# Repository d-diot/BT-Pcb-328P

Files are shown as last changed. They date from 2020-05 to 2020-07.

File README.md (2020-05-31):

# d-diot BT-Pcb-328P

Kicad project files of the d-diot BT-Pcb-328P board.
The board is part of the [d-diot project](https://www.d-diot.com).
See the [blog post](https://www.d-diot.com/2019/11/09/bt-pcb-328p/) or the dedicated [wiki page](https://wiki.d-diot.com/hardware/pcb/mysensors/bt_pcb_328p) to know more about this board.

pcbfront

pcbrear

See the latest [release](https://github.com/d-diot/BT-Pcb-328P/releases) to download the gerber files to manufacture this board.

## Applications of this PCB:

[MySensors](https://www.mysensors.org/) battery powered and [3d printable](https://www.thingiverse.com/thing:3968135) wireless [Multisensor](https://wiki.d-diot.com/sensors_and_actuators/mysensors/d-diot_battery_powered_multisensor) for motion, light, temperature and humidity detection.
MySensors is compatible with a lot of open source home automation software like Home Assistant (which is the one included in the [d-diot hub](https://www.d-diot.com/2020/05/24/d-diot-hub-v-2-0/) and [image](https://www.d-diot.com/?s=d-diot+image)), OpenHAB, Domoticz, etc... See [here](https://www.mysensors.org/controller) for a complete list.

Multisensor

## Firmware

The [repository](https://github.com/d-diot/BT-Pcb-328P-firmware) of the firmware associated to this board is here.

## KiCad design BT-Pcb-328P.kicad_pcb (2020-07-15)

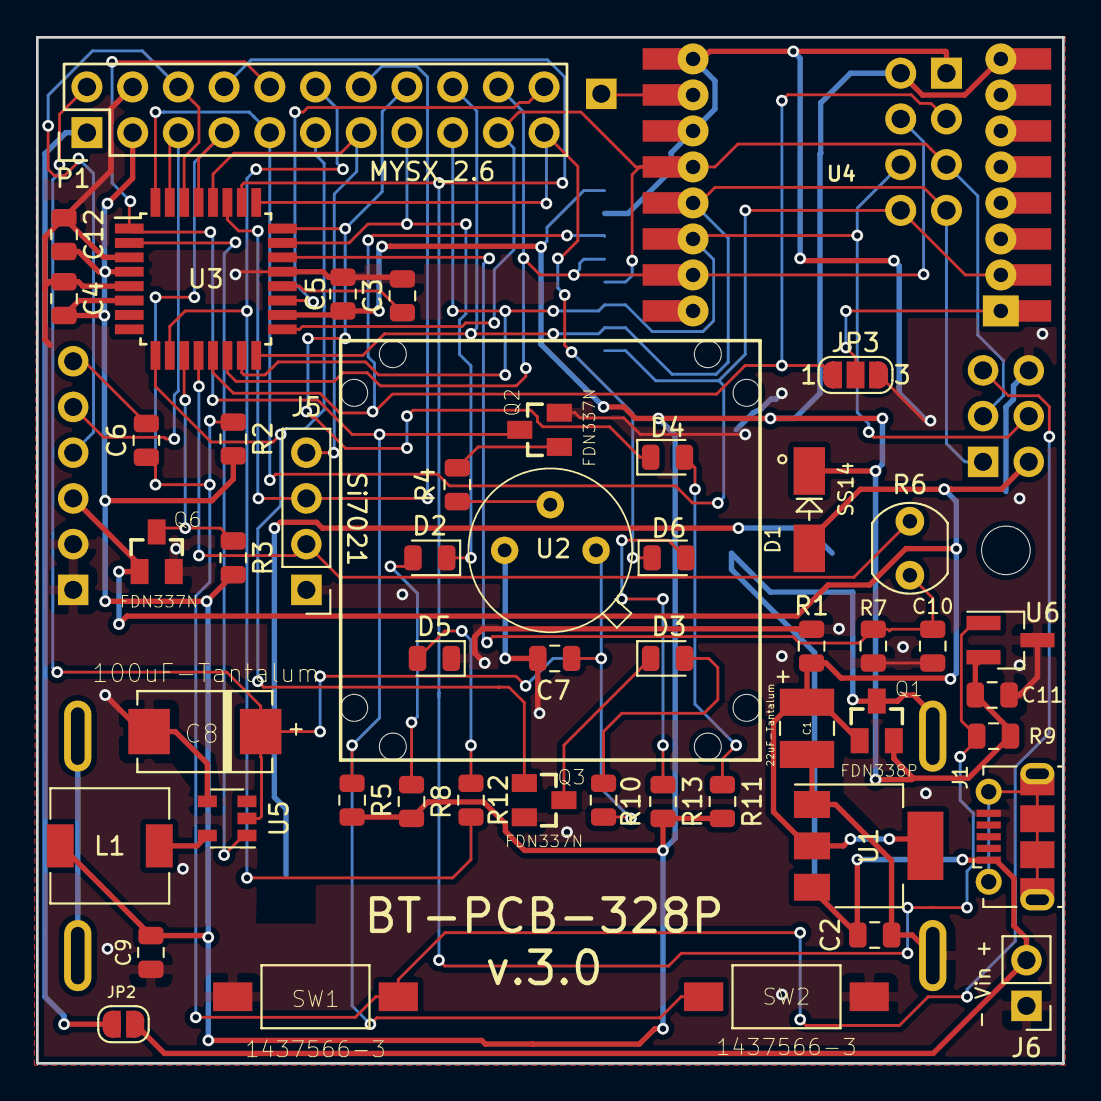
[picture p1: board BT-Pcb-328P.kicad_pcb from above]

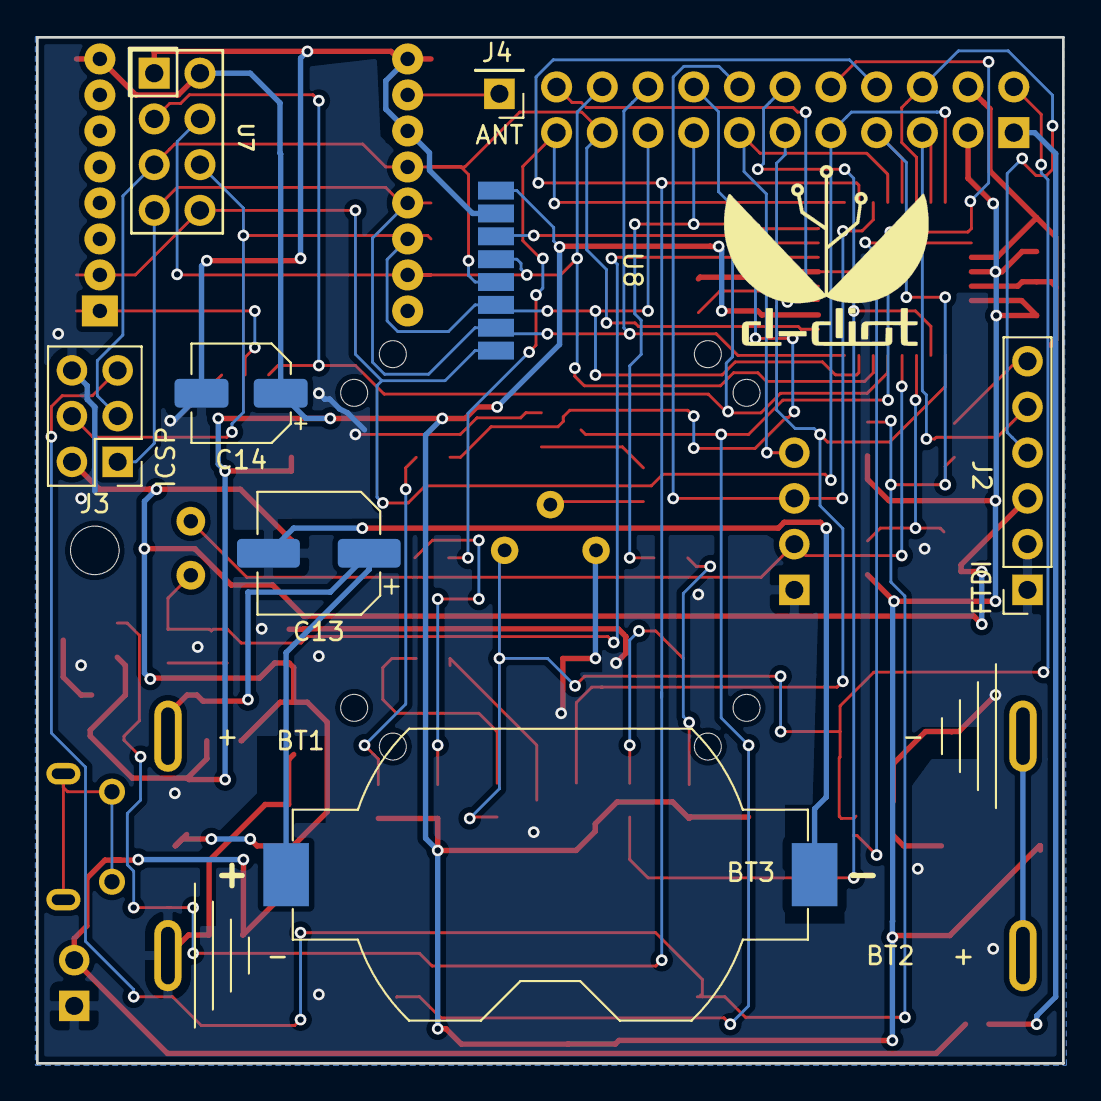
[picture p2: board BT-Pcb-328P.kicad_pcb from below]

Board: 2 copper layers, 57.0 x 57.0 mm, 60 parts (10 on the bottom side), 44 nets.

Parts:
BT1, BT2: AAA Cell; AAA-Keystone-5204-5226-NO-SILK
BT3: CR2032; BatteryHolder_Keystone_1058_1x2032
C1: 22uF-Tantalum; CAPPC3528X210N
C2, C9: 10uF; C_0805_2012Metric
C3, C4, C5, C6, C7, C10, C11, C12: 0.1uF; C_0805_2012Metric
C8: 100uF-Tantalum; TAJD107K016RNJV
C13: 100uF; CP_Elec_6.3x5.4
C14: 47uF; CP_Elec_5x5.4
D1: SS14
D2: R-LED; LED_0805_2012Metric
D3: B-LED; LED_0805_2012Metric
D4, D5: Y-LED; LED_0805_2012Metric
D6: G-LED; LED_0805_2012Metric
J1: USB_B_Micro; USB_Micro-B_Molex-105017-0001
J2: FTDI; PinSocket_1x06_P2.54mm_Vertical
J3: ICSP; PinHeader_2x03_P2.54mm_Vertical
J4: ANT; PinHeader_1x01_P2.54mm_Vertical
J5: Si7021; PinHeader_1x04_P2.54mm_Vertical
J6: Vin; PinHeader_1x02_P2.54mm_Vertical
JP2: Vraw; SolderJumper-2_P1.3mm_Open_RoundedPad1.0x1.5mm
JP3: Radio-rst; SolderJumper-3_P1.3mm_Open_RoundedPad1.0x1.5mm_NumberLabels
L1: 22uH; L_6.3x6.3_H3
P1: MYSX_2.6
Q1: FDN338P; SSOT-3
Q2, Q3, Q6: FDN337N; SSOT-3
R1, R2, R4, R9: 10K; R_0805_2012Metric
R3, R5: 20K; R_0805_2012Metric
R6: R_PHOTO; R_LDR_5.0x4.1mm_P3mm_Vertical
R7: 56K; R_0805_2012Metric
R8, R11, R12, R13: 330; R_0805_2012Metric
R10: 120; R_0805_2012Metric
SW1, SW2: 1437566-3; SW_1437566-3
U1: AMS1117-3.3; SOT-223-3_TabPin2
U2: AS312; PIR-AS312-3PIN
U3: ATmega328P-AU; TQFP-32_7x7mm_P0.8mm
U4: RFM69HW; RFM69HW_SMD_ThroughHole_Handsoldering
U5: ME2188C33; SOT-23-5
U6: ATSHA204A; SOT-23_Handsoldering
U7: NRF24L01
U8: NRF24L01; NRF24L01-SMD

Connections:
+3.3V: C7.2, C8.1, P1.2, R10.2, U2.1, U5.2
A0: D2.1, P1.15, U3.23
A1: D4.1, P1.16, U3.24
A2: D6.1, P1.21, U3.25
A3: P1.8, R9.2, U3.26, U6.1
A4-SDA: J5.3, P1.14, U3.27
A5-SCL: J5.4, P1.13, U3.28
A6: P1.22, U3.19
A7: C10.2, R6.2, R7.1, U3.22
D0-RXD: J2.4, P1.6, U3.30
D1-TXD: J2.5, P1.5, U3.31
D2: P1.9, U3.32, U4.2, U7.8, U8.8
D3: P1.10, Q2.3, R5.1, SW2.2, U3.1
D4: U3.2, U5.1
D5: P1.11, Q3.1, U3.9
D6: P1.12, R12.2, U3.10
D8: J5.2, R6.1, U3.12
D9: JP3.1, U3.13, U7.3, U8.3
DTR: C6.2, J2.6
Ext-Pwr: Q6.3, R3.1, U3.11
GND: BT2.2, BT3.2, C1.2, C2.2, C3.2, C4.1, C5.1, C7.1, C8.2, C9.1, C10.1, C11.1, C12.1, C13.2, C14.2, D5.1, J1.5, J2.1, J2.2, J3.6, J5.1, J6.1, JP3.3, P1.4, Q2.2, Q3.2, Q6.2, R1.1, R7.2, SW1.1, SW2.1, U1.1, U2.3, U3.3, U3.5, U3.21, U4.9, U4.11, U5.4, U6.3, U7.1, U8.1
MISO: J3.1, P1.18, U3.16, U4.13, U7.7, U8.7
MOSI: J3.4, P1.17, U3.15, U4.14, U7.6, U8.6
NSS: P1.20, U3.14, U4.15, U7.4, U8.4
unnamed: BT1.1, BT3.1, C13.1, Q1.3
unnamed: BT1.2, BT2.1
unnamed: C1.1, D1.2, J2.3, J3.2, Q1.1, Q6.1, R1.2, U1.2
unnamed: C2.1, J1.1, J6.2, JP2.2, U1.3
unnamed: C3.1, U3.20
unnamed: D2.2, R8.1
unnamed: D3.1, Q3.3
unnamed: D3.2, R10.1
unnamed: D4.2, R11.1
unnamed: D5.2, R12.1
unnamed: D6.2, R13.1
unnamed: J4.1, U4.10
unnamed: JP3.2, U4.1
unnamed: L1.2, U5.5
unnamed: Q2.1, R4.1
unnamed: R4.2, U2.2
RESET: C6.1, J3.5, P1.7, R2.1, SW1.2, U3.29
SCK: J3.3, P1.19, U3.17, U4.12, U7.5, U8.5
VCC: C4.2, C5.2, C9.2, C11.2, C12.2, C14.1, D1.1, L1.1, P1.3, Q1.2, R2.2, R3.2, R5.2, R8.2, R9.1, R11.2, R13.2, U3.4, U3.6, U3.18, U4.8, U6.2, U7.2, U8.2
Vraw: JP2.1, P1.1

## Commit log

2019-07-07 Development 1
    [BT-Pcb-328P.kicad_pcb, BT-Pcb-328P.sch]
2019-07-14 Development 2
    [BT-Pcb-328P.sch]
2019-07-14 Development 3
    [BT-Pcb-328P.kicad_pcb, BT-Pcb-328P.sch]
2019-07-14 Development 5
    [BT-Pcb-328P.kicad_pcb, BT-Pcb-328P.sch]
2019-07-17 Development 6
    [BT-Pcb-328P-B.Cu.gbr, BT-Pcb-328P-B.Mask.gbr, BT-Pcb-328P-B.Paste.gbr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]
2019-07-19 BP-Pcb-328P v.1.0
    [BT-Pcb-328P-B.Cu.gbr, BT-Pcb-328P-B.Mask.gbr, BT-Pcb-328P-B.Paste.gbr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]
2019-07-20 Added Vin + and - text
    [BT-Pcb-328P-B.Cu.gbr, BT-Pcb-328P-B.Mask.gbr, BT-Pcb-328P-B.Paste.gbr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]
2019-09-05 added HTML BOM
2019-09-14 board v.2.0
    [BT-Pcb-328P-B.Cu.gbr, BT-Pcb-328P-B.Mask.gbr, BT-Pcb-328P-B.Paste.gbr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]
2019-10-02 board v.3.0
    [BT-Pcb-328P-B.Cu.gbr, BT-Pcb-328P-B.Mask.gbr, BT-Pcb-328P-B.Paste.gbr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]
2019-10-02 readded nrf24l01 smd footprint
    [BT-Pcb-328P-B.Cu.gbr, BT-Pcb-328P-B.Mask.gbr, BT-Pcb-328P-B.Paste.gbr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]
2020-07-15 added gerber files suitable for manufacturing with PCBWay
    [BT-Pcb-328P-B_Cu.gbl, BT-Pcb-328P-B_Mask.gbs, BT-Pcb-328P-B_Paste.gbp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]
